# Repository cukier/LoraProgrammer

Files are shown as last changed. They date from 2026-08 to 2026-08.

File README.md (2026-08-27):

# LoraProgrammer

Firmware ESP32 (ESP-IDF) para programar e configurar módulos de rádio LoRa, expondo a configuração através de um servidor HTTP em Wi-Fi (SoftAP/STA), acessível também via mDNS (`http://<hostname>.local/`).

Dois rádios são suportados; apenas um é compilado por build, escolhido no `menuconfig`:

| Rádio | Interface | Como funciona |
|---|---|---|
| **RF1276 / YL_800IL** — [AppConWireless](https://www.appconwireless.com/) (*padrão*) | UART | Módulo com MCU próprio. O ESP32 lê/escreve os parâmetros (baudrate, paridade, frequência, spreading factor, modo, largura de banda, ID, Net ID, potência) pelo protocolo de comandos com header `0xAF`; os dados de payload são transparentes (bytes crus na mesma UART). |
| **LoRa127X-C1 / SX1276** — [NiceRF](https://www.nicerf.com/) | SPI nativa | Modem SX1276 controlado diretamente pelo ESP32 (componente `dernasherbrezon/sx127x`). Não tem memória de configuração: "programar" significa aplicar os parâmetros (frequência, largura de banda, SF, coding rate, sync word, preâmbulo, potência, CRC) a cada boot e em runtime via `POST /lora`. |

### Selecionar o rádio

```bash
cd src
idf.py menuconfig   # → "KLORA Configuration" → "LoRa radio module"
idf.py build
```

Sem `menuconfig`, o build usa o RF1276 (`CONFIG_KLORA_RADIO_RF1276=y`). Os pinos
(UART ou SPI) e os parâmetros de rádio ficam no mesmo menu, e são aplicados no
boot. A escolha do rádio também está exposta como variável de CMake, então o
`main/CMakeLists.txt` compila só o back end selecionado (`kuart.c` + `RF1216.c`
ou `klora_sx127x.c`).

### API HTTP (igual para os dois rádios)

| Método | Rota | Descrição |
|---|---|---|
| `GET`  | `/info` | RAM livre, versão do firmware, IP, uptime, hora local |
| `GET`  | `/lora` | Configuração atual do rádio (JSON) |
| `POST` | `/lora` | Aplica/grava parâmetros do rádio (corpo JSON, qualquer subconjunto) |
| `GET`  | `/lora/rxtx` | Hex dump do último pacote recebido pelo ar |
| `POST` | `/lora/rxtx` | Transmite um payload — corpo JSON `{"message": "..."}` |
| `POST` | `/ota` | Atualização de firmware |
| `POST` | `/reboot` | Reinicia o dispositivo após 5 s |

O formato do JSON de `/lora` difere entre os rádios (parâmetros distintos), mas a
saída do `GET` sempre volta a valer como corpo do `POST` para o mesmo back end.

## Estrutura do repositório

```
src/        Firmware ESP-IDF (projeto CMake)
  main/     Componente principal (código-fonte)
sch/        Projeto de hardware em KiCad
.github/    Workflows de CI (build do firmware e exports do KiCad)
```

## Firmware

Projeto ESP-IDF padrão. Para compilar:

```bash
cd src
idf.py build
idf.py -p <PORT> flash monitor
```

O CI (`.github/workflows/firmware.yml`) compila o firmware a cada push/PR em `src/**` e publica os binários (`.bin`, `bootloader.bin`, `partition-table.bin`) como artifact.

## Hardware

Esquemático e PCB em `sch/` (KiCad 9). O CI (`.github/workflows/hardware.yml`) exporta Gerbers, drill files e BOM a cada push/PR em `sch/**`.

## Configuração

`radio.json` documenta o formato dos parâmetros de rádio (back end RF1276) expostos pela API HTTP do firmware.

## Licença

MIT — veja [LICENSE](LICENSE).

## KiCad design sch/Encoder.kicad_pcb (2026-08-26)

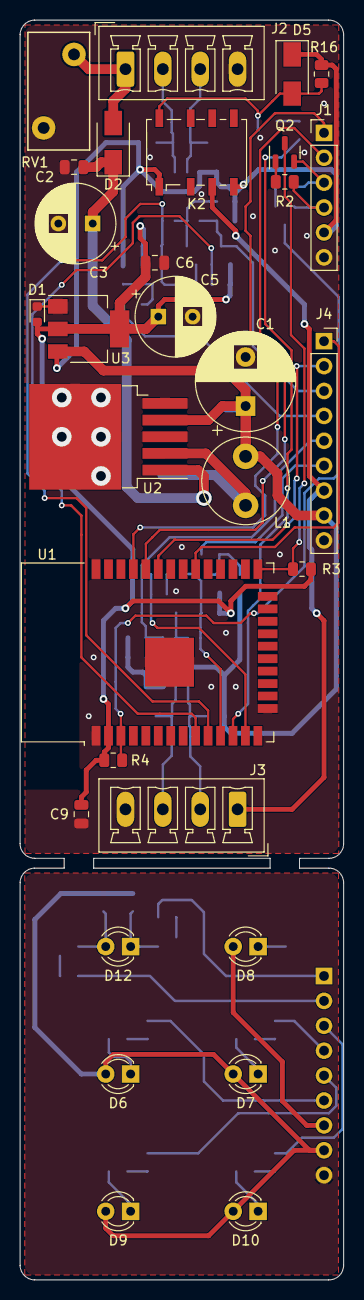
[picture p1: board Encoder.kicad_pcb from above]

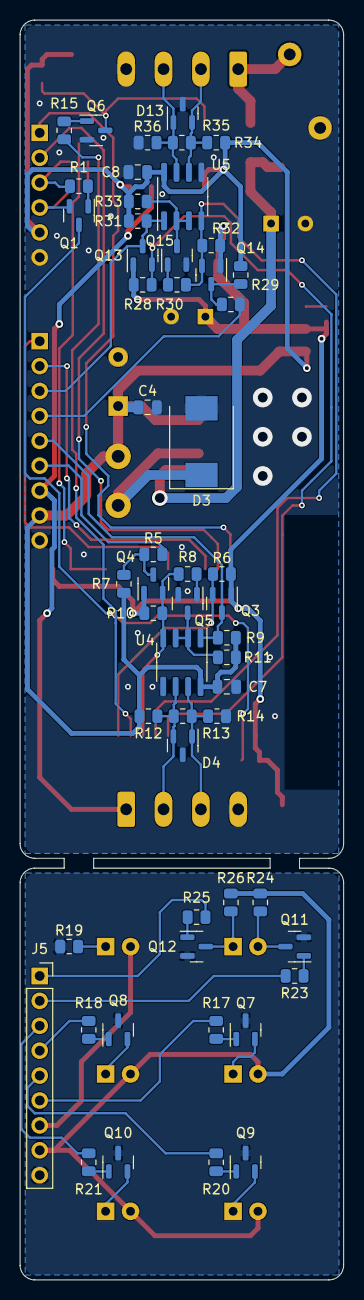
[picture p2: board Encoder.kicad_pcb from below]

Board: 2 copper layers, 33.0 x 128.5 mm, 84 parts (54 on the bottom side), 60 nets.

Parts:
C1: 1000uF; CP_Radial_D10.0mm_P5.00mm
C2, C4, C6, C7, C8, C9: 100nF; C_0805_2012Metric
C3, C5: 470uF; CP_Radial_D8.0mm_P3.50mm
D1: ESD9B3.3ST5G; D_0603_1608Metric
D2, D5: US1M; D_SMA
D3: SS35; D_SMC
D4, D13: SM712; SOT-23
D6: TX1; LED_D3.0mm
D7: TX2; LED_D3.0mm
D8: ENC; LED_D3.0mm
D9, D10: RX2; LED_D3.0mm
D12: HEART_BEAT; LED_D3.0mm
J1: PROG; PinHeader_1x06_P2.54mm_Vertical
J2: PWR; PhoenixContact_MCV_1,5_4-G-3.81_1x04_P3.81mm_Vertical
J3: ENC; PhoenixContact_MCV_1,5_4-G-3.81_1x04_P3.81mm_Vertical
J4: CON_I; PinSocket_1x09_P2.54mm_Vertical
J5: CON_O; PinSocket_1x09_P2.54mm_Vertical
K2: G6K-2; Relay_DPDT_Omron_G6K-2F-Y
L1: 100uH; L_Radial_D8.7mm_P5.00mm_Fastron_07HCP
Q1, Q2, Q5, Q15: MMBT2222ALT1G; SOT-23
Q3, Q4, Q13, Q14: MMBF170; SOT-23
Q6, Q11, Q12: BC817; SOT-23
Q7, Q8, Q9, Q10: BC807; SOT-23
R1, R2, R3, R4, R5, R6, R7, R9, R10, R11, R16, R17, R18, R20, R21, R23, R25, R27, R28, R29, R31, R32, R33: 10k; R_0805_2012Metric
R8, R15, R19, R24, R26, R30: 1k; R_0805_2012Metric
R12, R14, R34, R36: 560R; R_0805_2012Metric
R13, R35: 120R; R_0805_2012Metric
RV1: 10D390K; RV_Disc_D12mm_W6.3mm_P7.5mm
U1: ESP32-WROOM-32
U2: LM2596S-5; TO-263-5_TabPin3
U3: AP1117-33; SOT-223-3_TabPin2
U4, U5: SP3485EN; SOIC-8_3.9x4.9mm_P1.27mm

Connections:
+3V3: C5.1, C6.1, C9.1, D1.2 (A2), Q3.1 (G), Q4.1 (G), Q13.1 (G), Q14.1 (G), R3.1, R4.1, R6.2, R10.2, R28.2, R32.2, U1.2 (VDD), U3.2 (VO)
+5V: C1.1, C4.1, C7.1, C8.1, D5.1 (K), J1.5, J4.8, K2.1, K2.4, L1.2, R7.2, R9.2, R11.2, R12.2, R16.2, R29.2, R31.2, R33.2, R34.2, U2.4 (FB), U3.3 (VI), U4.8 (VCC), U5.8 (VCC)
+5VA: D6.2 (A), D7.2 (A), D9.2 (A), D10.2 (A), J5.8, R24.2, R26.2
+24V: D2.2 (A), J2.1, RV1.1
/A_ENC: D4.2 (A2), J3.2, R12.1, R13.2, U4.6 (A)
/A_PLC: D13.2 (A2), J2.2, R34.1, R35.2, U5.6 (A)
/B_ENC: D4.1 (A1), J3.3, R13.1, R14.2, U4.7 (B)
/B_PLC: D13.1 (A1), J2.3, R35.1, R36.2, U5.7 (B)
/Core/BOOT: Q2.3 (C), R3.2, U1.25 (IO0)
/Core/DTR: J1.3, Q2.2 (E), R1.2
/Core/RTS: J1.4, Q1.2 (E), R2.2
/Core/RX: J1.2, U1.34 (RXD0/IO3)
/Core/TX: J1.1, U1.35 (TXD0/IO1)
/Core/~RESET: Q1.3 (C), R4.2, U1.3 (EN)
/ENC_OK: J3.1, J4.7, K2.3
/EN_ENC: R15.2, U1.12 (IO27)
/HB_1: J4.2, U1.33 (IO21)
/HB_2: J4.1, U1.30 (IO18)
/IHM/ENC_OK: D8.2 (A), J5.7
/IHM/HB1: J5.2, R23.2
/IHM/HB2: J5.1, R25.2
/IHM/RX1: J5.5, R20.2
/IHM/RX2: J5.3, R21.2
/IHM/TX1: J5.6, R17.2
/IHM/TX2: J5.4, R18.2
/RXO_ENC: J4.5, Q3.3 (D), R9.1, U4.1 (RO)
/RXO_PLC: J4.3, Q13.3 (D), R31.1, U5.1 (RO)
/RX_ENC: Q3.2 (S), R6.1, U1.13 (IO14)
/RX_PLC: Q13.2 (S), R28.1, U1.9 (IO33)
/TXO_ENC: J4.6, R5.2
/TXO_PLC: J4.4, R27.2
/TX_ENC: Q4.2 (S), R8.2, R10.1, U1.11 (IO26), U4.4 (DI)
/TX_PLC: Q14.2 (S), R30.2, R32.1, U1.10 (IO25), U5.4 (DI)
/Transdutor Enc/~RE/DE: Q5.3 (C), R11.1, U4.2 (~RE), U4.3 (DE)
/Transdutor PLC/~RE/DE: Q15.3 (C), R33.1, U5.2 (~RE), U5.3 (DE)
GND: C1.2, C2.2, C3.2, C4.2, C5.2, C6.2, C7.2, C8.2, C9.2, D1.1 (A1), D3.2 (A), D4.3 (common), D13.3 (common), J1.6, J2.4, J3.4, J4.9, Q5.2 (E), Q6.2 (E), Q15.2 (E), R14.1, R36.1, RV1.2, U1.1 (GND), U1.15 (GND), U1.38 (GND), U1.39 (GND), U2.3 (GND), U2.5 (~ON/OFF), U3.1 (GND), U4.5 (GND), U5.5 (GND)
GNDA: J5.9, Q7.3 (C), Q8.3 (C), Q9.3 (C), Q10.3 (C), Q11.2 (E), Q12.2 (E), R19.1
unnamed: C2.1, C3.1, D2.1 (K), U2.1 (VIN)
unnamed: D3.1 (K), L1.1, U2.2 (OUT)
unnamed: D5.2 (A), K2.8, Q6.3 (C), R16.1
unnamed: D6.1 (K), Q7.2 (E)
unnamed: D7.1 (K), Q8.2 (E)
unnamed: D8.1 (K), R19.2
unnamed: D9.1 (K), Q9.2 (E)
unnamed: D10.1 (K), Q10.2 (E)
unnamed: D12.2 (A), Q11.3 (C), R24.1
unnamed: D12.1 (K), Q12.3 (C), R26.1
unnamed: Q1.1 (B), R1.1
unnamed: Q2.1 (B), R2.1
unnamed: Q4.3 (D), R5.1, R7.1
unnamed: Q5.1 (B), R8.1
unnamed: Q6.1 (B), R15.1
unnamed: Q7.1 (B), R17.1
unnamed: Q8.1 (B), R18.1
unnamed: Q9.1 (B), R20.1
unnamed: Q10.1 (B), R21.1
unnamed: Q11.1 (B), R23.1
unnamed: Q12.1 (B), R25.1
unnamed: Q14.3 (D), R27.1, R29.1
unnamed: Q15.1 (B), R30.1

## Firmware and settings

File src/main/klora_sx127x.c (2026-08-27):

/* NiceRF LoRa127X-C1 (Semtech SX1276) back end for klora.h.
 *
 * Selected by CONFIG_KLORA_RADIO_SX127X. The chip is driven directly over native
 * SPI with the dernasherbrezon/sx127x component - there is no on-module config
 * store, so the settings under "KLORA Configuration" are applied at every boot
 * and can be re-applied at runtime through POST /lora.
 *
 * REST surface (same paths as the RF1276 back end in kuart.c):
 *   GET  /lora        - current radio configuration + TX/RX counters as JSON
 *   POST /lora        - apply any subset of the config fields (JSON body)
 *   GET  /lora/rxtx   - hex dump (text/plain) of the last received payload
 *   POST /lora/rxtx   - transmit {"message": "..."} as one LoRa packet
 */

#include <ctype.h>
#include <stdio.h>
#include <stdlib.h>
#include <string.h>

#include "freertos/FreeRTOS.h"
#include "freertos/semphr.h"
#include "freertos/task.h"

#include "driver/gpio.h"
#include "driver/spi_master.h"
#include "esp_http_server.h"
#include "esp_log.h"
#include "esp_timer.h"

#include <sx127x.h>

#include "cJSON.h"

#include "include/klora.h"

static const char *TAG = "klora";

#define KLORA_CHECK(expr)                                                       \
  do {                                                                          \
    int _err = (expr);                                                          \
    if (_err != SX127X_OK) {                                                    \
      ESP_LOGE(TAG, #expr " failed: 0x%x", _err);                               \
      return ESP_FAIL;                                                          \
    }                                                                          \
  } while (0)

/* Guards s_device (every sx127x_*() call, since the library isn't reentrant)
 * and s_info. Recursive because klora_interrupt_task holds it across
 * sx127x_handle_interrupt(), which synchronously calls the rx/tx callbacks on
 * the same task - a plain mutex would deadlock there. */
static SemaphoreHandle_t s_lock;
static SemaphoreHandle_t s_tx_done_sem;
static sx127x s_device;
static TaskHandle_t s_interrupt_task;

static struct klora_state {
  uint32_t frequency_hz;
  uint32_t bandwidth_hz;
  int spreading_factor;  /* 6-12 */
  int coding_rate_denom; /* 5-8, meaning 4/5..4/8 */
  uint8_t sync_word;
  uint16_t preamble_length;
  int tx_power_dbm;
  bool crc_enabled;

  const char *opmode_str;

  uint32_t tx_count;
  uint32_t tx_bytes;
  uint32_t tx_errors;
  uint32_t last_tx_ms;

  uint32_t rx_count;
  uint16_t last_rx_len;
  int16_t last_rx_rssi;
  float last_rx_snr;
  uint32_t last_rx_ms;
  uint8_t last_rx_payload[255];
} s_info;

static sx127x_sf_t klora_sf_from_int(int sf) {
  switch (sf) {
  case 6:
    return SX127X_SF_6;
  case 7:
    return SX127X_SF_7;
  case 8:
    return SX127X_SF_8;
  case 9:
    return SX127X_SF_9;
  case 10:
    return SX127X_SF_10;
  case 11:
    return SX127X_SF_11;
  default:
    return SX127X_SF_12;
  }
}

static sx127x_cr_t klora_cr_from_denom(int denom) {
  switch (denom) {
  case 5:
    return SX127X_CR_4_5;
  case 6:
    return SX127X_CR_4_6;
  case 7:
    return SX127X_CR_4_7;
  default:
    return SX127X_CR_4_8;
  }
}

static void klora_rx_callback(void *ctx, uint8_t *data, uint16_t data_length) {
  sx127x *device = (sx127x *)ctx;
  int16_t rssi = 0;
  float snr = 0;
  sx127x_rx_get_packet_rssi(device, &rssi);
  sx127x_lora_rx_get_packet_snr(device, &snr);

  xSemaphoreTakeRecursive(s_lock, portMAX_DELAY);
  s_info.rx_count++;
  s_info.last_rx_len = data_length;
  s_info.last_rx_rssi = rssi;
  s_info.last_rx_snr = snr;
  s_info.last_rx_ms = (uint32_t)(esp_timer_get_time() / 1000);
  memcpy(s_info.last_rx_payload, data,
         data_length > sizeof(s_info.last_rx_payload)
             ? sizeof(s_info.last_rx_payload)
             : data_length);
  xSemaphoreGiveRecursive(s_lock);

  ESP_LOGI(TAG, "rx: %u bytes, rssi=%d snr=%.1f", (unsigned)data_length, rssi,
           (double)snr);
}

static void klora_tx_callback(void *ctx) {
  (void)ctx;
  xSemaphoreGive(s_tx_done_sem);
}

static void IRAM_ATTR klora_isr(void *arg) {
  (void)arg;
  BaseType_t woken = pdFALSE;
  vTaskNotifyGiveFromISR(s_interrupt_task, &woken);
  portYIELD_FROM_ISR(woken);
}

static void klora_interrupt_task(void *arg) {
  (void)arg;
  for (;;) {
    if (ulTaskNotifyTake(pdTRUE, portMAX_DELAY) > 0) {
      xSemaphoreTakeRecursive(s_lock, portMAX_DELAY);
      sx127x_handle_interrupt(&s_device);
      xSemaphoreGiveRecursive(s_lock);
    }
  }
}

static void klora_reset_chip(void) {
  gpio_config_t io_conf = {
      .pin_bit_mask = 1ULL << CONFIG_KLORA_RESET_GPIO,
      .mode = GPIO_MODE_OUTPUT,
  };
  gpio_config(&io_conf);
  gpio_set_level(CONFIG_KLORA_RESET_GPIO, 0);
  vTaskDelay(pdMS_TO_TICKS(5));
  gpio_set_level(CONFIG_KLORA_RESET_GPIO, 1);
  vTaskDelay(pdMS_TO_TICKS(10));
}

static esp_err_t klora_init_spi(spi_device_handle_t *out_handle) {
  spi_bus_config_t bus_cfg = {
      .mosi_io_num = CONFIG_KLORA_MOSI_GPIO,
      .miso_io_num = CONFIG_KLORA_MISO_GPIO,
      .sclk_io_num = CONFIG_KLORA_SCK_GPIO,
      .quadwp_io_num = -1,
      .quadhd_io_num = -1,
      .max_transfer_sz = 0,
  };
  /* DMA required: without it, ESP32 SPI transactions cap at the 64-byte
   * hardware FIFO (SPI_DMA_DISABLED), which silently fails any LoRa payload
   * above that. */
  esp_err_t err = spi_bus_initialize(SPI2_HOST, &bus_cfg, SPI_DMA_CH_AUTO);
  if (err != ESP_OK) {
    return err;
  }

  spi_device_interface_config_t dev_cfg = {
      .clock_speed_hz = 2 * 1000 * 1000,
      .spics_io_num = CONFIG_KLORA_SS_GPIO,
      .queue_size = 16,
      .command_bits = 0,
      .address_bits = 8,
      .dummy_bits = 0,
      .mode = 0,
  };
  return spi_bus_add_device(SPI2_HOST, &dev_cfg, out_handle);
}
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

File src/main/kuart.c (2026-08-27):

#include "freertos/FreeRTOS.h"
#include "freertos/queue.h"
#include "freertos/semphr.h"
#include "freertos/task.h"

#include "driver/gpio.h"
#include "driver/uart.h"

#include "esp_http_server.h"
#include "esp_log.h"

#include "RF1276.h"
#include "include/klora.h"
#include "loraprogrammer.h"

#include "cJSON.h"

#include <string.h>

#define BUF_SIZE (1024)
#define PATTERN_CHR_NUM (3)

static const gpio_num_t tx_pin = CONFIG_KLORA_RF1276_TX_GPIO;
static const gpio_num_t rx_pin = CONFIG_KLORA_RF1276_RX_GPIO;
static const gpio_num_t en_pin = CONFIG_KLORA_RF1276_EN_GPIO;
static const int aux_pin = CONFIG_KLORA_RF1276_AUX_GPIO;
static const uart_port_t uart_port = CONFIG_KLORA_RF1276_UART_NUM;
static const char *TAG = "kauart";

static QueueHandle_t uart0_queue = NULL;
static SemaphoreHandle_t uart_semphr = NULL;
static radio_data_t radio = {0};
static char buffer_rx[BUF_SIZE] = {0};
static size_t buffer_rx_len = 0;

static void enRadio() {
  gpio_set_level(en_pin, 1);
  ESP_LOGI(TAG, "Ligado");
}

static void disableRaidio() {
  gpio_set_level(en_pin, 0);
  ESP_LOGI(TAG, "Desligado");
}

static esp_err_t change_uart(uint32_t new_baudrate, char new_parity,
                             int new_data, int new_stop) {
  esp_err_t err = ESP_ERR_NOT_SUPPORTED;

  uart_wait_tx_done(uart_port, 100 / portTICK_PERIOD_MS);
  err = uart_set_baudrate(uart_port, new_baudrate);

  if (err != ESP_OK)
    return err;

  if ((new_parity == 'n') || (new_parity == 'N'))
    err = uart_set_parity(uart_port, UART_PARITY_DISABLE);
  else if ((new_parity == 'e') || (new_parity == 'E'))
    err = uart_set_parity(uart_port, UART_PARITY_EVEN);
  else if ((new_parity == 'o') || (new_parity == 'O'))
    err = uart_set_parity(uart_port, UART_PARITY_ODD);
  else
    return ESP_ERR_INVALID_ARG;

  if (err != ESP_OK)
    return err;

  if (new_data == 5)
    err = uart_set_word_length(uart_port, UART_DATA_5_BITS);
  else if (new_data == 6)
    err = uart_set_word_length(uart_port, UART_DATA_6_BITS);
  else if (new_data == 7)
    err = uart_set_word_length(uart_port, UART_DATA_7_BITS);
  else if (new_data == 8)
    err = uart_set_word_length(uart_port, UART_DATA_8_BITS);
  else
    return ESP_ERR_INVALID_ARG;

  if (err != ESP_OK)
    return err;

  if (new_stop == 1)
    err = uart_set_stop_bits(uart_port, UART_STOP_BITS_1);
  else if (new_stop == 2)
    err = uart_set_stop_bits(uart_port, UART_STOP_BITS_2);
  else
    return ESP_ERR_INVALID_ARG;

  if (err != ESP_OK)
    return err;

  return ESP_OK;
}

void k_uart_rx_task(void *pvParameters) {
  uart_event_t uartEvent;
  uint8_t *dtmp = NULL;

  (void)pvParameters;

  vTaskDelay(pdMS_TO_TICKS(500));
  enRadio();

  for (;;) {
    if (xQueueReceive(uart0_queue, (void *)&uartEvent, (TickType_t)100) ==
        pdTRUE) {
      if (uartEvent.type == UART_DATA) {
        dtmp = (uint8_t *)malloc(uartEvent.size + 1);
        uart_read_bytes(uart_port, (void *)dtmp, uartEvent.size, portMAX_DELAY);
      }
    }

    if (dtmp != NULL) {
      // ESP_LOG_BUFFER_HEXDUMP(TAG, dtmp, uartEvent.size, ESP_LOG_INFO);

      if (strstr((char *)dtmp, "YL_800IL") != NULL) {
        int baud = 0;
        char parity = '0';
        int data = 0;
        int stop = 0;

        sscanf((char *)dtmp, "%d %c %d %d YL_800IL", &baud, &parity, &data,
               &stop);

        ESP_LOGI(TAG, "Radio encontrado em baud %d parity %c data %d stop %d",
                 baud, parity, data, stop);

        esp_err_t err = change_uart(baud, parity, data, stop);

        if (err != ESP_OK)
          ESP_LOGW(TAG, "Erro ao configurar uart %d", uart_port);
        else {
          int len = -1;
          uint8_t *request = RF1276_make_radio_read_command(&len);

          configASSERT(request != NULL);
          vTaskDelay(pdMS_TO_TICKS(100));

          if (len > 0) {
            ESP_ERROR_CHECK(uart_flush_input(uart_port));
            uart_write_bytes(uart_port, (const void *)request, len);
          }
        }
      } else if (strstr((char *)dtmp, "\xaf\xaf\x00\x00\xaf") != NULL) {
        if (uartEvent.size == RF1276_COMMAND_SIZE) {
          uart_word_length_t word_length = UART_DATA_BITS_MAX;
          uart_stop_bits_t stop_bits = UART_STOP_BITS_MAX;
          esp_err_t err = ESP_OK;
          radio_data_t *ptr_radio = NULL;

          ptr_radio = RF1276_parse_radio(&dtmp[8], RF1276_DATA_SIZE);

          err = uart_get_word_length(uart_port, &word_length);
          err |= uart_get_stop_bits(uart_port, &stop_bits);

          if (err == ESP_OK) {
            ptr_radio->serial.length = word_length + 5;
            ptr_radio->serial.stop = stop_bits;
          }

          if (ptr_radio != NULL) {
            if (xSemaphoreTake(uart_semphr, pdMS_TO_TICKS(200)) == pdTRUE) {
              memcpy(&radio, ptr_radio, sizeof(radio_data_t));
              xSemaphoreGive(uart_semphr);
            }

            ESP_LOGI(TAG, "Radio detectado");
            free(ptr_radio);
          }
        }
      } else {
        if (xSemaphoreTake(uart_semphr, pdMS_TO_TICKS(200)) == pdTRUE) {
          buffer_rx_len =
              (uartEvent.size > BUF_SIZE) ? BUF_SIZE : uartEvent.size;
          memcpy(buffer_rx, dtmp, buffer_rx_len);
          xSemaphoreGive(uart_semphr);
        }
      }

      free(dtmp);
      dtmp = NULL;
    }
  }

  vTaskDelete(NULL);
}

esp_err_t klora_init(void) {

  uart_config_t uart_config = {
      .baud_rate = CONFIG_KLORA_RF1276_DEFAULT_BAUD,
      .data_bits = UART_DATA_8_BITS,
      .parity = UART_PARITY_DISABLE,
      .stop_bits = UART_STOP_BITS_1,
      .flow_ctrl = UART_HW_FLOWCTRL_DISABLE,
      .source_clk = UART_SCLK_DEFAULT,
  };
  uint64_t out_pins = 1ULL << en_pin;
  if (aux_pin >= 0) {
    out_pins |= 1ULL << aux_pin;
  }
  gpio_config_t configEn = {.pin_bit_mask = out_pins,
                            .mode = GPIO_MODE_OUTPUT,
                            .pull_up_en = GPIO_PULLUP_DISABLE,
                            .pull_down_en = GPIO_PULLDOWN_DISABLE,
                            .intr_type = GPIO_INTR_DISABLE};

  uart_semphr = xSemaphoreCreateMutex();
  configASSERT(uart_semphr != NULL);
  xSemaphoreGive(uart_semphr);

  ESP_ERROR_CHECK(uart_driver_install(uart_port, BUF_SIZE * 2, BUF_SIZE * 2, 20,
                                      &uart0_queue, 0));
  configASSERT(uart0_queue != NULL);
  ESP_ERROR_CHECK(uart_param_config(uart_port, &uart_config));
  ESP_ERROR_CHECK(uart_set_pin(uart_port, tx_pin, rx_pin, UART_PIN_NO_CHANGE,
                               UART_PIN_NO_CHANGE));
  ESP_ERROR_CHECK(uart_enable_pattern_det_baud_intr(uart_port, '\n',
                                                    PATTERN_CHR_NUM, 9, 0, 0));
  ESP_ERROR_CHECK(uart_pattern_queue_reset(uart_port, 20));
  ESP_ERROR_CHECK(gpio_config(&configEn));
  if (aux_pin >= 0) {
    gpio_set_level(aux_pin, 1);
  }

  disableRaidio();

  ESP_LOGI(TAG, "Init...");

  xTaskCreate(k_uart_rx_task, "k_uart_rx_task", 2048, NULL, 5, NULL);

  return ESP_OK;
}
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

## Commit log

2026-08-26 Lora Programmer V1
    [Encoder.kicad_pcb, Encoder.kicad_sch, alim.kicad_sch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]
2026-08-26 Fix hardware CI: run docker container as the runner's own UID/GID
    The kicad/kicad image defaults to a non-root user (uid 1000), which
    doesn't match the checked-out sch/ directory's owner on the GitHub
    runner, so kicad-cli couldn't create the gerbers/ output dir
    (EACCES). Passing --user "$(id -u):$(id -g)" makes the container run
    as the same user that owns the mounted files, avoiding both the
    permission error and leaving root-owned output behind.
